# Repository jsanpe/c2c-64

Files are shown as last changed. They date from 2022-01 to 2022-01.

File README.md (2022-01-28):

# C2C-64
A Composite & S-Video to Component Video transcoder to feed older analog signals into your OSSC.

Designed with the C-64 in mind, it also supports composite and s-video signals from other systems, including the N64. A compatibility chart will soon be available in the wiki section of this project.

<p float="left">
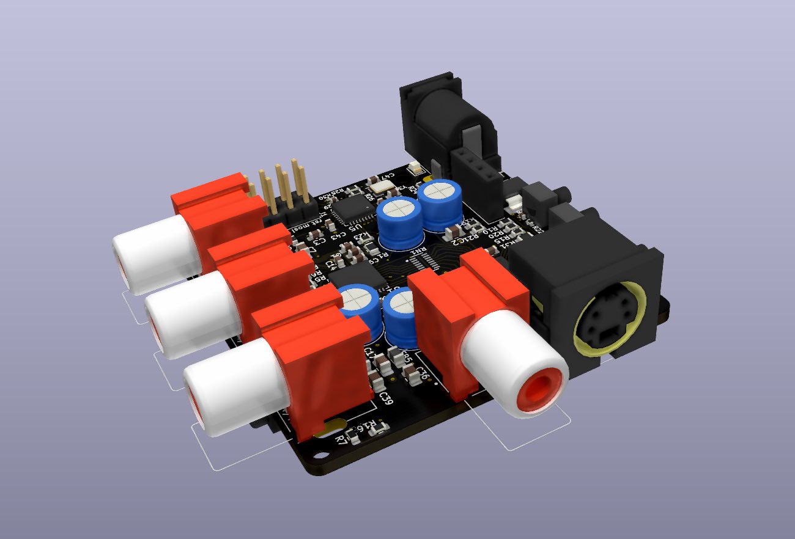
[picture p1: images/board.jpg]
C2C-64 Board Image
    
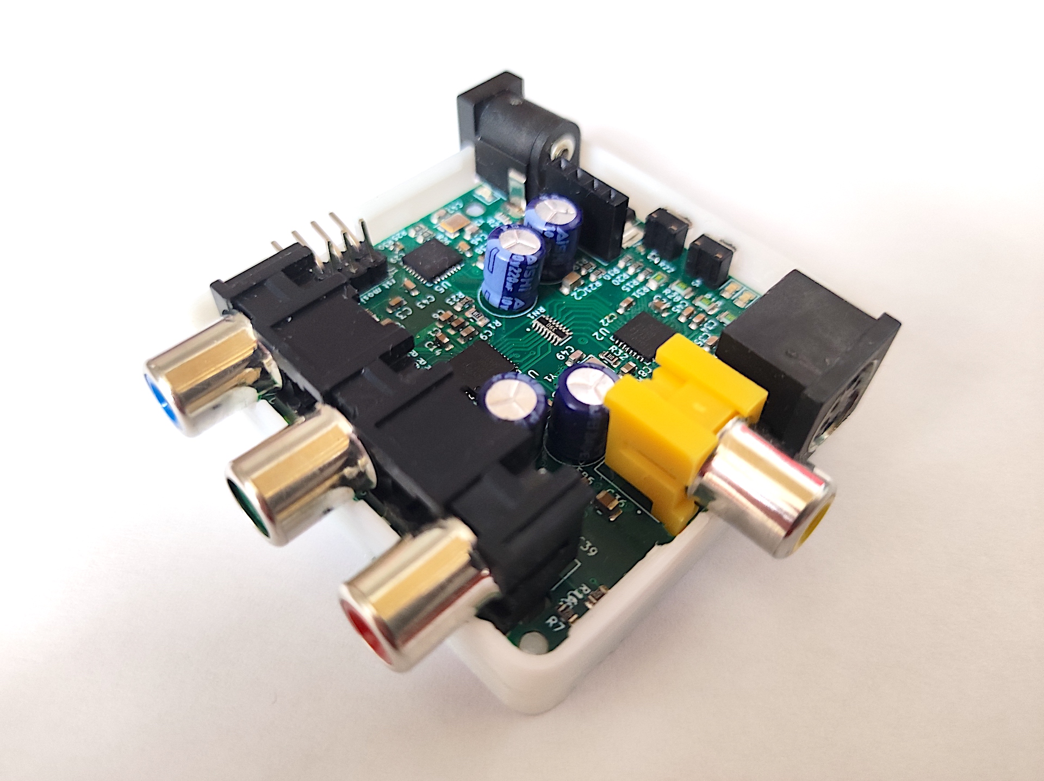
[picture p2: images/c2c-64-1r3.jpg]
C2C-64 Case Image
    
</p> 

## Description

This is an open hardware implementation of a board to convert Composite and S-Video signals into Component video. The component output from C2C-64 can be directly connected to an OSSC, effectively adding compatibility with Composite and S-Video input to this great scaler.

C2C-64 was primarily design as a simple way to connect a C64 to and OSSC. Most of the testing has been done in this platform, and presets have been chosen with it in mind. I have conducted some tests with other machines (N64, SNES, Dreamcast), although not as extensive.

C2C-64 uses a simple pipeline of video decoder and encoder to transform the input composite or S-video signals into component video. What this means in practice is that the analog input is converted to digital format and fed to the encoder to transform it into a different analog signal. This conversion is NOT lossless. However, it enables anyone to conveniently hook such signals directly into the OSSC without tinkering with the internals of their devices. 

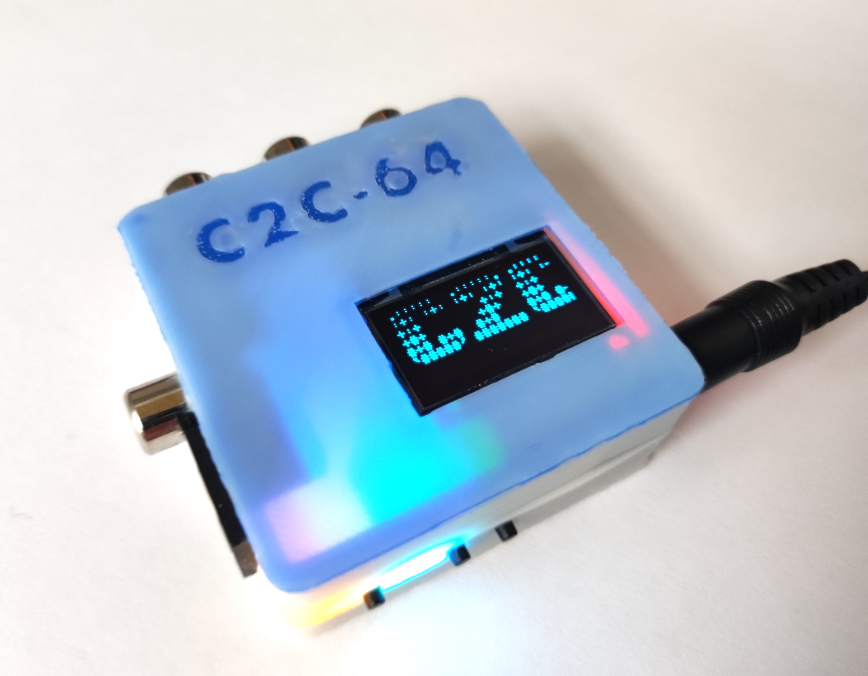
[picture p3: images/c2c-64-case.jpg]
C2C-64 Case Image


## Getting your C2C-64

This is an open project, in this repository you will find everything you need in order to build your own C2C-64.

It is important to note that building this requires ninja-grade soldering skills, especially to get those QFN ICs properly connected to the board. Also, sourcing some of the components may be a bit trickier than usual. In particular, the ADV7180 IC is unsupported by Analog anymore and probably AliExpress is the only place where it can be found at this point. There is an ADV7280(A) based version of the C2C (2R) that will be soon released, but the price of this IC is way more expensive.

I am in the process of building a first batch of 35 boards (version 1R3) that I will be selling to anyone interested in supporting the project. Reach me directly if you are interested at `com2com64@gmail.com`. I will be compiling a list and start shipping them on a first come first served basis.

You can also support the project by donating through my KoFi page 



## Comparison to Koryuu

In terms of functionality, C2C-64 provides a similar experience to the commercial product [Koryuu](https://videogameperfection.com/products/koryuu-transcoder/). However, there are notable differences between C2C-64 and Koryuu:
- C2C-64 is fully Open and Free, both Software and Hardware. Note, C2C-64 is still WiP so some parts are either missing or still in beta.
- C2C-64 has been designed to be as affordable as possible. The PCB is a 50x50mm 4 layer design, for which you can normally get special deals on PCB manufacturers. With the current shortage of electronic parts, it is difficult to estimate the total BOM cost given the huge price fluctuations. It should be possible to get the board built for well under $50 in small amounts even in these adverse conditions (half the price of Koryuu).
- The video decoding IC in the C2C-64 is the older Adv7180, compared to the more modern Adv7280 of the Koryuu. I made extensive tests, and for the intent and purposes of this board I don't think the extra cost of Adv7280 (5x the price of Adv7180) is justified. This assumption holds as long as you connect the output to an OSSC, which has de-interlacing and scaling options way beyond the possibilities of the Adv7280. An Adv7280-based version of C2C-64  already exists and will be released at some point in the future (it needs more testing and firmware changes)
- C2C-64 adds a big number of usability features to the mix (described below) making it way more flexible in terms of configuration options

## User interface

One important improvement of C2C-64 over Koryuu is the inclusion of powerful interfacing options. The board provides three main ways of allowing user interaction:
- Side switches: There are 3 switches that allow the user to perform the two most common actions: alternating the source video signal between composite and S-video; and selecting configuration profiles stored in the board EEPROM.
- UART connection: A computer can be hooked up to the board using the uart pin headers available for this purpose. Using a VT100 compatible terminal, users can configure tenths of parameters about how the video decoding/encoding is performed using menus. Such settings can then be stored as profiles in the EEPROM to be easily accessed using the side switches.
- OLED Screen: The board supports the connection of an OPTIONAL 0.96'' oled display. When the board detected that an OLED display has been connected, it will show a reduced version of the menu system offered through the UART connection, making the use of a computer to configure settings completely unnecessary.

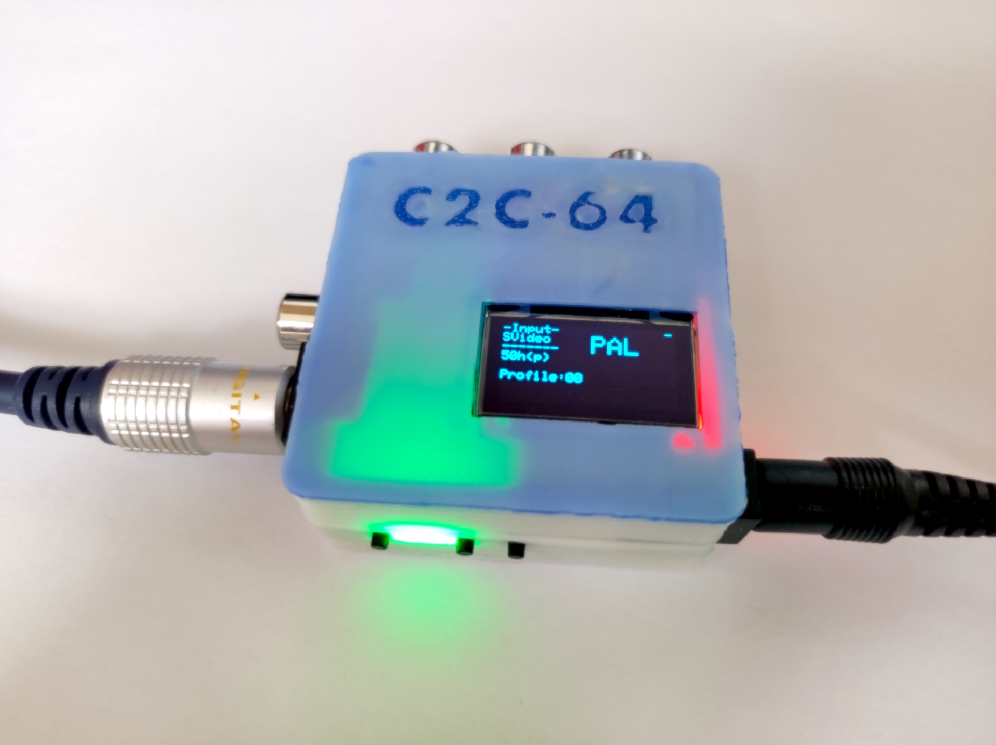
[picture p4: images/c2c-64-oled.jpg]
C2C-64 Case Image


There are also 4 leds that are used to show important signals about the operation of the board

## Important notice

This project is still WiP. The repository contains only a beta version of the firmware required to run the board. Keep checking this page for updates.

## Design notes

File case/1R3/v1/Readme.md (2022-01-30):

# Simple Case for C2C-64

It is recommended to use a case to protect the electronics of the C2C-64 from potential shorts that could result in permanent damage. This folder contains a simple case design to this end. The case is made up of two parts, bottom and top. The bottom part is enough to give good protection to the board. To insert the board on the bottom part, first push the side with the 3xRCA output and make sure that the minijack connector on the bottom side fits in the appropriate hole in the case. Then, gently press on the opposite side of the board, slightly pressing the buttons so they don't block the board on its way down. After this procedure is finished, the board will be firmly attached to the case.

There are 3 top case examples provided:
- A simple design without space for OLED screen or C2C logo
- A second design, with support for the OLED screen but no logo
- A third design, with support for the OLED screen and logo

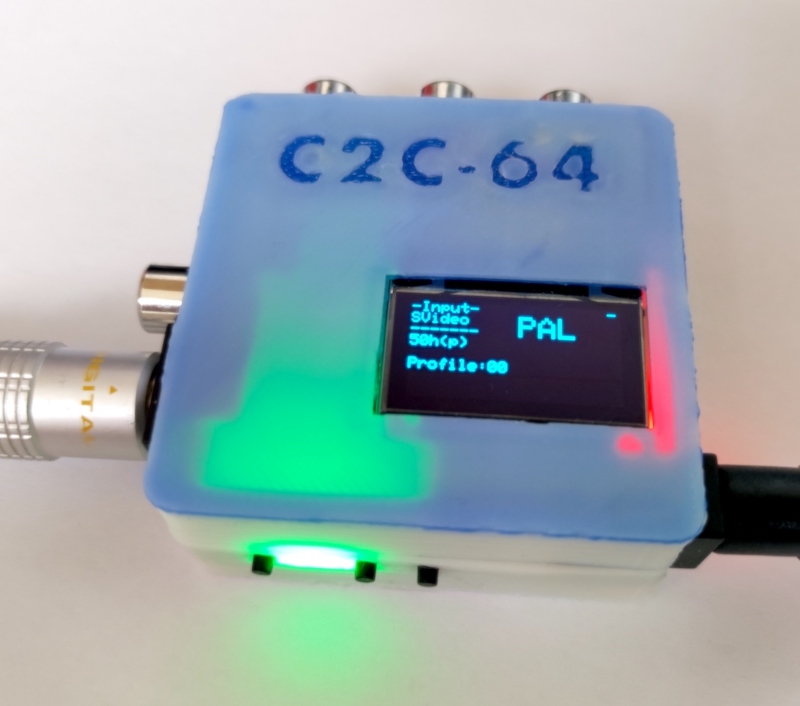
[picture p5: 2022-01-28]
images/c2c-64-oled-small.jpg

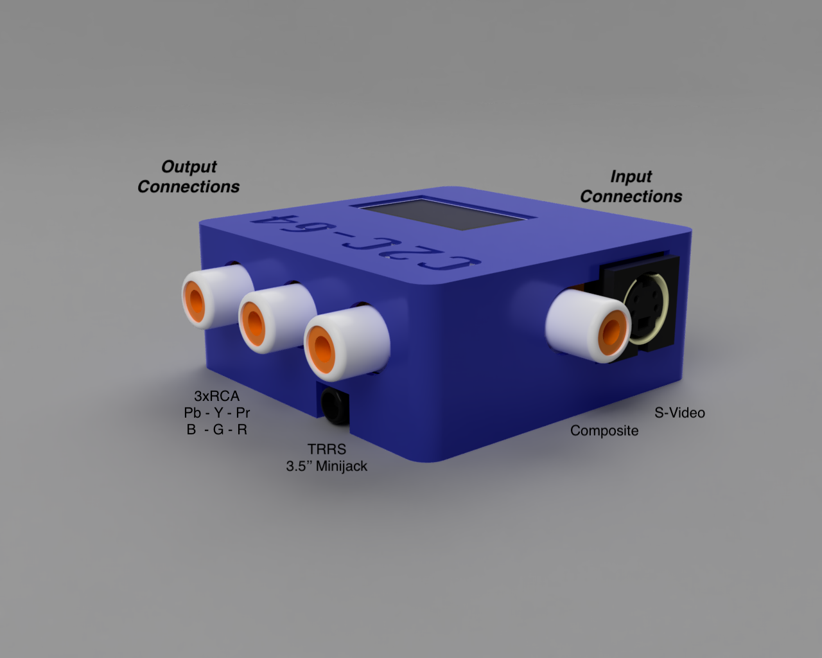
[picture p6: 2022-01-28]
images/input-output.png

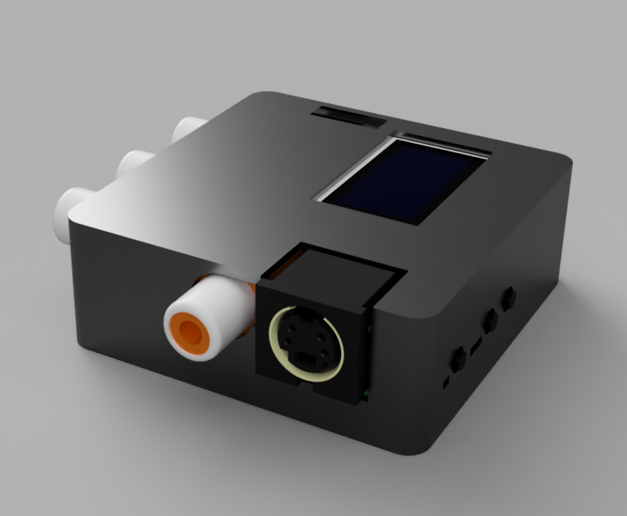
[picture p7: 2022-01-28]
images/case.png

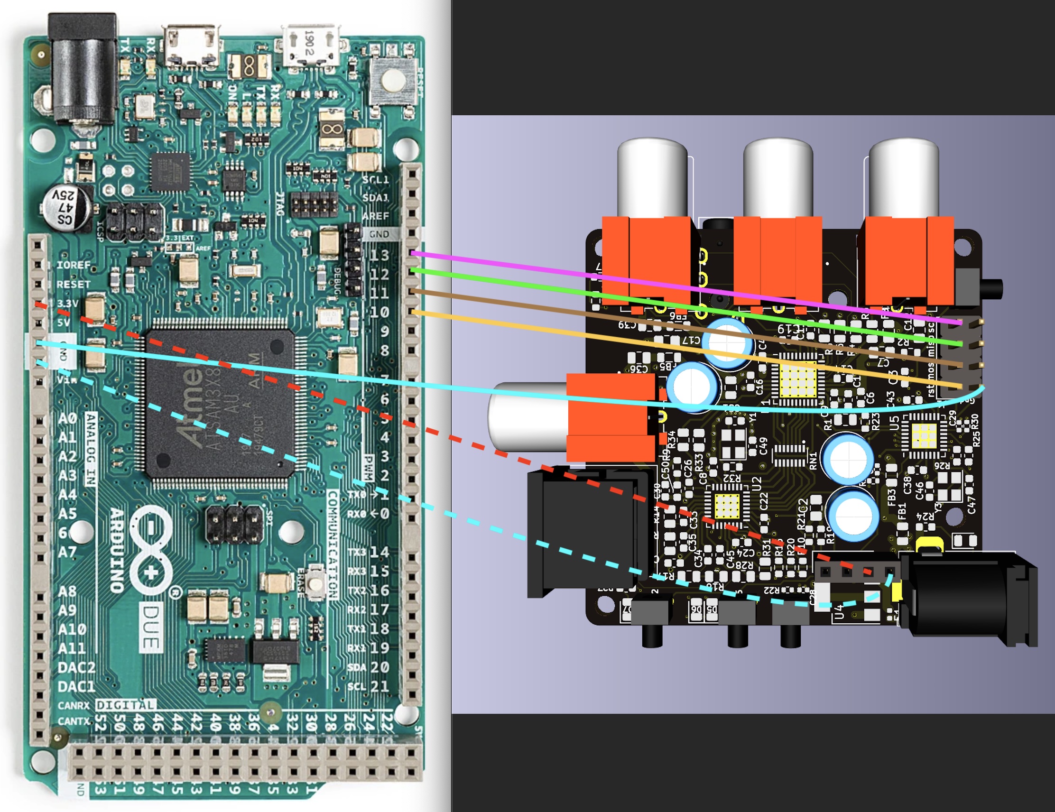
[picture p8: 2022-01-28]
images/icsp_connections.jpg

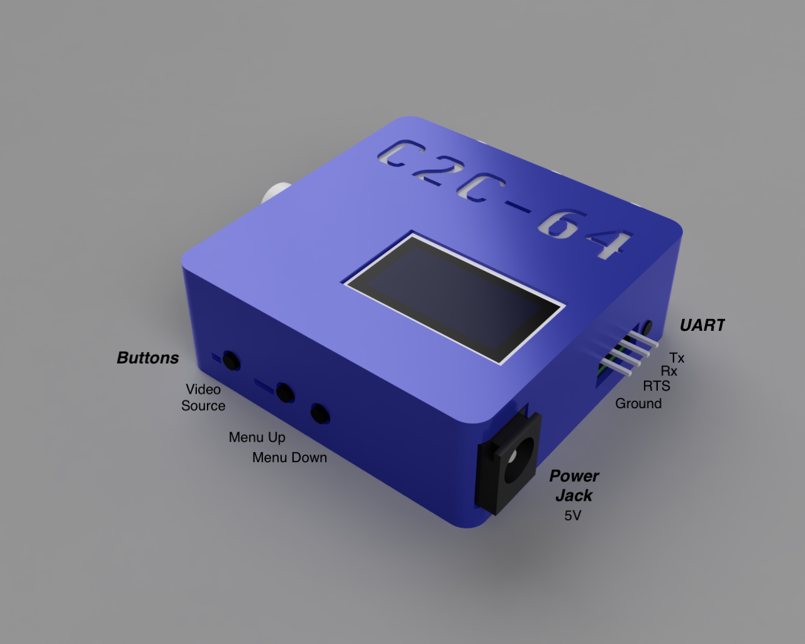
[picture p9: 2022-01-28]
images/buttons.png

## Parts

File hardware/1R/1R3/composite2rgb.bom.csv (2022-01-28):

Value | Designator | Footprint | Comments
12n | C1 | Capacitor_SMD:C_0603_1608Metric | <=5% tolerance, >=X7R
2.2n | C11 | Capacitor_SMD:C_0603_1608Metric
22u | C2,C7,C12,C17 | Capacitor_SMD:C_0805_2012Metric
82n | C30 | Capacitor_SMD:C_0603_1608Metric | <=5% tolerance, >=X7R
100nF | C3,C33,C34,C35,C38,C43,C45 | Capacitor_SMD:C_0603_1608Metric
22u | C36,C39 | Capacitor_SMD:C_0805_2012Metric
10uF | C4,C8,C9,C14,C16,C19,C22,C24,C26,C31 | Capacitor_SMD:C_0603_1608Metric
220uF | C37,C40,C41,C42 | Capacitor_THT:C_Radial_D6.3mm_H5.0mm_P2.50mm
100nF | C28,C29,C44 | Capacitor_SMD:C_0402_1005Metric
30pF | C46,C47,C49,C51 | Capacitor_SMD:C_0603_1608Metric
10n | C50 | Capacitor_SMD:C_0603_1608Metric | <=5% tolerance, >=X7R
150n | C6 | Capacitor_SMD:C_0603_1608Metric | <=5% tolerance, >=X7R
BAT54S | D1,D2,D3 | Package_TO_SOT_SMD:SOT-23
LED_R | D4 | LED_SMD:LED_0805_2012Metric
LED_B | D5 | LED_SMD:LED_0805_2012Metric
LED_G | D6 | LED_SMD:LED_0805_2012Metric
LED_Y | D7 | LED_SMD:LED_0805_2012Metric
1.5A | F1 | Fuse:Fuse_0402_1005Metric
Ferrite_Bead | FB1,FB2,FB3,FB4,FB5,FB6 | Inductor_SMD:L_0805_2012Metric
MountingHole | H1,H2,H3,H4 | MountingHole:MountingHole_2.5mm
Conn_02x04_Top_Bottom | J1 | Connector_PinHeader_2.54mm:PinHeader_2x04_P2.54mm_Vertical
RCJ-041 | J10 | RCJ-041:CUI_RCJ-041
Mini-DIN-4 | J4 | RCJ-041:CUI_MD-50S
Power | J6 | Connector_BarrelJack:BarrelJack_Horizontal
Conn_01x04_Female | J8 | Connector_PinSocket_2.54mm:PinSocket_1x04_P2.54mm_Vertical
169 | R1 | Resistor_SMD:R_0805_2012Metric
39 | R12,R18,R31 | Resistor_SMD:R_0805_2012Metric
36 | R14,R17,R28 | Resistor_SMD:R_0805_2012Metric
10k | R23 | Resistor_SMD:R_0603_1608Metric
330 | R24 | Resistor_SMD:R_0603_1608Metric
120 | R25 | Resistor_SMD:R_0603_1608Metric
220 | R26,R27 | Resistor_SMD:R_0603_1608Metric
10k | R22,R29,R30 | Resistor_SMD:R_0402_1005Metric
510 | R3 | Resistor_SMD:R_0805_2012Metric
1M | R32 | Resistor_SMD:R_0603_1608Metric
33 | R33,R34 | Resistor_SMD:R_0805_2012Metric
75 | R4,R5,R6 | Resistor_SMD:R_0805_2012Metric
4k7 | R2,R7,R10,R15,R16,R19,R20,R21 | Resistor_SMD:R_0603_1608Metric
1.69K | R9 | Resistor_SMD:R_0603_1608Metric
33 | RN1 | RCJ-041:RESCAXE50P380X160X55-16N
SW_Push | SW1,SW2,SW4,SW5 | Button_Switch_THT:mini-btn
ADV7393-Video | U1 | Package_DFN_QFN:QFN-40-1EP_6x6mm_P0.5mm_EP4.6x4.6mm_ThermalVias
ADV7180-32LFCSP | U2 | Package_CSP:LFCSP-32-1EP_5x5mm_P0.5mm_EP3.1x3.1mm_ThermalVias
TLV70018_SOT23-5 | U3,U6 | Package_TO_SOT_SMD:SOT-23-5
AMS1117-3.3 | U4 | Package_TO_SOT_SMD:SOT-223-3_TabPin2
ATmega328PB-MU | U5 | Package_DFN_QFN:QFN-32-1EP_5x5mm_P0.5mm_EP3.1x3.1mm
3xRCA_CONN | U7 | RCJ-041:TRRS-PJ-320A
3xCUI-RCJ | U8 | RCJ-041:3xCUI_RCJ-041
Crystal_GND24_Small | Y1 | Crystal:Crystal_SMD_3225-4Pin_3.2x2.5mm
16Mhz | Y2 | Crystal:Crystal_C38-LF_D3.0mm_L8.0mm_Vertical
16Mhz | Y3 | Crystal:Crystal_SMD_3225-4Pin_3.2x2.5mm
28.63 | Y6 | Crystal:Crystal_C38-LF_D3.0mm_L8.0mm_Vertical

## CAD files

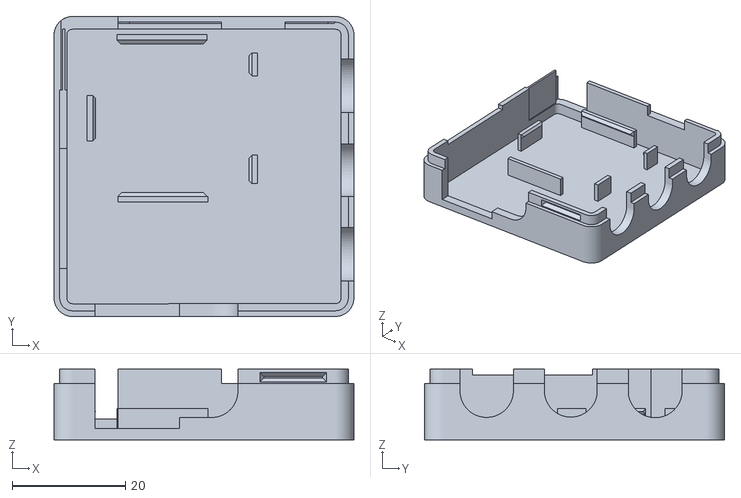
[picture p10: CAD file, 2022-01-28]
case/1R3/v1/Case_Top_Simple.stl
53.0 x 53.0 x 12.5

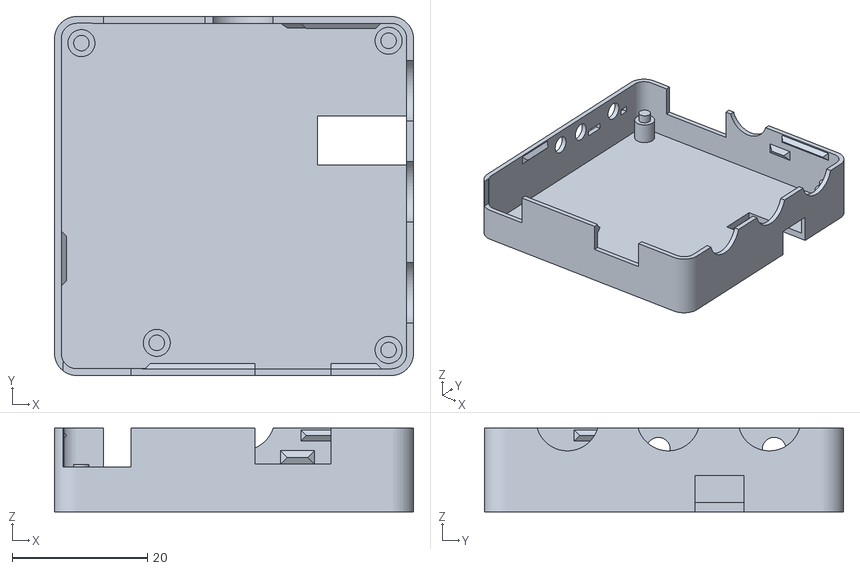
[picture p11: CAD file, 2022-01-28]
case/1R3/v1/Case_Bottom.stl
53.0 x 53.0 x 12.3

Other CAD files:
case/1R3/v1/Case_Top_Oled_Logo.stl
case/1R3/v1/Case_Top_Oled.stl

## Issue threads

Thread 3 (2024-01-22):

BOM Questions

ezcGman, 2024-01-22:
Hey there,

I'm currently collecting parts to build some of these awesome board (thanks for making these available!!).

I do have some questions about some parts:

> Ferrite_Bead	FB1,FB2,FB3,FB4,FB5,FB6	Inductor_SMD:L_0805_2012Metric

Do you have a bit more specs or an exact part number for these? LCSC (obviously) spits out a million results for just an inductor ;)

> Crystal_GND24_Small	Y1	Crystal:Crystal_SMD_3225-4Pin_3.2x2.5mm

This one is missing the frequency, do you have that by any chance?

> 33	RN1	RCJ-041:RESCAXE50P380X160X55-16N

I can't find this one anywhere with that part number. I guess from the looks and the "16N" it's some kind of multiplexer?

> 16Mhz	Y2	Crystal:Crystal_C38-LF_D3.0mm_L8.0mm_Vertical
> 28.63	Y6	Crystal:Crystal_C38-LF_D3.0mm_L8.0mm_Vertical

Are those actually on the board still? I struggle to find them when looking at the gerbers in a gerber viewer. I was struggling to understand the package size / footprint of these, so I tried to find them on the board and see what they look lilke.

And on another note: In case you are using KiCad, I **highly** recommend using this plugin: https://github.com/openscopeproject/InteractiveHtmlBom

It's absolutely fantastic and generates interactive / HTML BOM files which are a tremendous help when soldering such a board. You can get an idea what they look like here (just download and open the HTML): https://github.com/ezcGman/lora-gateway/tree/master/pcbs/LoRa-Gateway-E32/ibom

Thanks and greetings,

Andy!

jsanpe, 2024-01-22:
Hi,
thanks for reaching out. Sorry about the poor state of the project, I unfortunately have little time these days to maintain/improve it.
Regarding your questions:
- For ferrites I used these: https://www.lcsc.com/product-detail/Ferrite-Beads_Sunlord-GZ2012D601TF_C1017.html but they seem to be out of stock nowadays. You should be able to find something with similar characteristics in lcsc (or elsewhere)
- For crystals, note that Y1 and Y6 are mutually exclusive. You should use one or the other, depending on availability. The freq is 28.636363Mhz. I have used this one in the past: C136080.
- The same applies to crystals Y2/Y3, you can choose either one. However, this crystal is not needed as the MPU internal oscilator is used by default. So, you can leave this (and the caps C46 and C47) unpopulated.
- RN1 is a resistor array. 33 ohm is recommended, but you can use something close to it if you don't find it. I actually have been using this part: C78520 which is 39ohm

I will try to use the plugin you recommend and push the output to github. I can't really commit to this, lot's of other stuff in my life right now.

jsanpe, 2024-01-22:
It was easier than I expected: https://github.com/jsanpe/c2c-64/tree/master/hardware/1R/1R3/bom

ezcGman, 2024-01-22:
> Hi, thanks for reaching out. Sorry about the poor state of the project, I unfortunately have little time these days to maintain/improve it. Regarding your questions:
>
> * For ferrites I used these: https://www.lcsc.com/product-detail/Ferrite-Beads_Sunlord-GZ2012D601TF_C1017.html but they seem to be out of stock nowadays. You should be able to find something with similar characteristics in lcsc (or elsewhere)

They're still in stock for me using that link, added them to the cart, thx!

> * For crystals, note that Y1 and Y6 are mutually exclusive. You should use one or the other, depending on availability. The freq is 28.636363Mhz. I have used this one in the past: C136080.

Oh ok. I just looked at the BOM, was there a note about that somewhere that I missed? I added the C136080 to the cart: https://www.lcsc.com/product-detail/Crystals_HELE-Harmony-Elec-X3S02863ADK1HA-X_C136080.html

> * The same applies to crystals Y2/Y3, you can choose either one. However, this crystal is not needed as the MPU internal oscilator is used by default. So, you can leave this (and the caps C46 and C47) unpopulated.

Ah ok. So that one is not even used at all? So there is really no need for it? I might just add it, because it's just a few cents, if there is the slightest chance for it to make any sense :)

> * RN1 is a resistor array. 33 ohm is recommended, but you can use something close to it if you don't find it. I actually have been using this part: C78520 which is 39ohm

Aaaaah yeah 🤦 That makes sense, thanks! LCSC doesn't have it in stock, will get it somewhere else.

Will continue adding everything to the cart, thanks already!!

Greetings,

Andy!

ezcGman, 2024-01-22:
Some questions on the fuse:
* Guessing 6v is fine, as everything is 5v on the board?
* Is the 1.5A the tripping or hold current? Guessing it's trip current?

Thanks!

jsanpe, 2024-01-23:
For fuse I used this: C311043. 6V is a bit tight, but you can always replace it if it blows too easily. At 1.5A you should use a fast fuse. The board consumption should be in the few mA range (300mA tops) but it's always higher when you switch it on, that's the reason I allow for some extra amps. You may want to go for a slower fuse with lower amp rating.

About Y2/Y3 the current firmware does NOT use them. The internal atmega oscillator is accurate enough to allow for UART to work fine at slow speeds. For all other intents and purposes the accuracy of the oscillator is simply irrelevant, as the MPU is only there to configure the Video encoder and decoder ICs. My recommendation: do not populate.

ezcGman, 2024-01-23:
One more sadly :D Do you by any chance have a link to the buttons you used? There are a quadrizillion buttons out there and finding the ones you used with the spacing... it's close to impossible :D Thanks!

jsanpe, 2024-01-23:
> One more sadly :D Do you by any chance have a link to the buttons you used? There are a quadrizillion buttons out there and finding the ones you used with the spacing... it's close to impossible :D Thanks!

These little f$ckers are hard to find, tell me about it. Try these: C961730

ezcGman, 2024-01-24:
Thanks for your extensive help!

I've ordered everything, most from LCSC and some connectors from AliExpress. I'm attaching the CSV of my LCSC order for people to easier re-order the components. Also, there are the items on AliExpress I ordered:

* https://www.aliexpress.com/item/1005004682978457.html
* https://www.aliexpress.com/item/4001206395694.html
* https://www.aliexpress.com/item/1005006152724809.html
* https://www.aliexpress.com/item/1005003406780797.html

[LCSC_Exported__20240124_210810.csv](https://github.com/jsanpe/c2c-64/files/14038775/LCSC_Exported__20240124_210810.csv)
**ATTENTION:** A few caps are missing from this CSV, as I still had them in stock here. Forgot which ones these were. I'll update this post as soon as I receive the order, so I can easily see what's missing, so what I need to get out of my personal stock.

ezcGman, 2024-01-26:
Will do! I've updated the CSV to now reflect the full components list, so people can just use that :) Closing this for now :)

whytheheckme, 2024-05-07:
@ezcGman Did you ever get this up and running? Do you have spare parts you'd like to sell (particularly a PCB?)

ezcGman, 2024-05-08:
> @ezcGman Did you ever get this up and running? Do you have spare parts you'd like to sell (particularly a PCB?)

Jepp, I did: https://github.com/jsanpe/c2c-64/issues/5

And yeah, I do have complete (just missing the screen, but that is easy to get via AliExpress) left over kits I can sell. Because I bought parts for 5 kits directly, the price per kit is actually super low, it's just below 20€! I can spare one, if you want it? I'm in Germany, so depending on where you are, shipping costs may be the same as the price for the kit ;)

whytheheckme, 2024-05-08:
> And yeah, I do have complete (just missing the screen, but that is easy to get via AliExpress) left over kits I can sell. Because I bought parts for 5 kits directly, the price per kit is actually super low, it's just below 20€! I can spare one, if you want it? I'm in Germany, so depending on where you are, shipping costs may be the same as the price for the kit ;)

Amazing! I just finished pricing out all of the parts and the PCB, and I really don't need more than one, so I think it would be worth it. I live in the US but have an address in Denmark you can send it to where I will be in about 10 days (I found I could generate a label for 12€ but you may be able to get it even cheaper!)

Can you drop me a line? jake.at.spam (at) gmail
Thank you!!

whytheheckme, 2024-05-10:
@ezcGman Just wanted to follow up, I'd love to connect and buy a kit set from you.

Closed 2024-01-26.

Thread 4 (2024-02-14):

Question about orientation of ICs

ezcGman, 2024-02-14:
Hey there (again) :)

I was just about to solder one of these and then realized that the PCB is missing the usual dot indicators to tell about the orientation of the ICs. I saw that the silkscreen/graveyard on one side is open instead of closed. Is that the orientation indicator?

Talking about this:
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

Thanks and greetings,

Andy!

jsanpe, 2024-02-15:
Yup, Kicad's default footprints indicate pin number 1 using the open angle, as you mentioned

ezcGman, 2024-02-15:
Ou, never realized. I also use KiCAD but that I never saw.
Thanks!! Off to the workbench then \o/

Closed 2024-02-15.

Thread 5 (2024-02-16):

Failing to program via UART (and maybe also to transfer the bootloader)

ezcGman, 2024-02-16:
Hey there,

it's me again... I finished building the board and everything looks fine, but I struggle a bit to get it flashed via UART. And now I'm not even sure if I did everything right for the fuses and bootlader.

I'm using this for reference: https://github.com/jsanpe/c2c-64/wiki/Programming-the-C2C-64

First, I don't have an Arduino DUE, but I googled a bit and it seems that you can also use an ESP8266 or ESP32 (which I work with A LOT) to achieve the same. So I successfully flashed the ArduinoISP sketch (it just compiles naturally, I just needed to change some pins) to a random ESP8266 (Actually a NodeMCU) I had using ArduinoIDE. Then (because you're using/referencing a platformio.ini file) I opened my VS.Code which I also use a lot to flash ESPs using platformio, so I'm pretty familiar with that.

That's how it's wired (c2c is powered using my bench PSU, set to 5v 2A):
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

I opened the "fuses_1R3" task, changed the upload_port to "COM4" (as I'm on Windows) and I could successfully run the "Set Fuses" and "Burn Bootloader" platform tasks (which is I guess what you're referencing in your guide). Both worked successfully, see the output at the end of this post.
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

I then took my FTDI dongle (which uses a FT232BL chip (https://www.aliexpress.com/item/32967622307.html)) and tried to flash the software via UART, but I always get the same error: `avrdude warning: attempt x of 10: not in sync: resp=0x00`

Yes, sadly my dongle doesn't have an easy way to wire RST, but it has the pin exposed, so I'm touching it manually. But no matter how often I try, I always get the same error. I also tried simply bridging RST of the c2c to GND manually but it never works. No matter how often I try and when... It never works. I even tried reversing TX/RX, just in case: Still nothing.

Then I thought, after reading your guide 100th time: "Did I actually flash the bootloader?", as I just used the platform task "Burn bootlader". I then got my ESP wired again, validated I can still execute "Set Fuses" and then just hit "Upload" (still under the "fuses_1R3" task), but it first failed with not finding the "SSD1306Ascii" library, because it's missing in the "fuses_1R3" task. Added it and hit "Upload" again. It compiled but then getting the same error as I got via UART: `avrdude warning: attempt x of 10: not in sync: resp=0x00`

I'm a bit lost what I'm doing wrong... Do you maybe have an idea what's happening? I don't think my board is broken, right? Otherwise I wouldn't be able to execute the platform tasks "Set Fuses" and "Burn Bootloader" successfully, right? :/

Which USB FTDI dongle are you using? I might just get a different one; not really trusting this one here with the weird RST pin...

Thanks so much again and greetings,

Andy!

P.S.:
Some outputs:
Set Fuses:
```
Executing task: C:\Users\andy\.platformio\penv\Scripts\platformio.exe run --target fuses --environment fuses_1R3

Warning! Ignore unknown configuration option `build_unflags` in section [platformio]
Warning! Ignore unknown configuration option `build_flags` in section [platformio]
Warning! Ignore unknown configuration option `monitor_port` in section [platformio]
Warning! Ignore unknown configuration option `monitor_speed` in section [platformio]
Processing fuses_1R3 (platform: atmelavr; framework: arduino; board: ATmega328PB)
--------------------------------------------------------------------------------------------------------------------------------------------------------------------------------------------------------------------------------------------------------------------------------------------------
Verbose mode can be enabled via `-v, --verbose` option
CONFIGURATION: https://docs.platformio.org/page/boards/atmelavr/ATmega328PB.html
PLATFORM: Atmel AVR (5.0.0) > ATmega328PB
HARDWARE: ATMEGA328PB 8MHz, 2KB RAM, 32KB Flash
PACKAGES:
 - framework-arduino-avr-minicore @ 3.0.0
 - tool-avrdude @ 1.70200.0 (7.2.0)
 - toolchain-atmelavr @ 1.70300.191015 (7.3.0)
LDF: Library Dependency Finder -> https://bit.ly/configure-pio-ldf
LDF Modes: Finder ~ chain, Compatibility ~ soft
Found 10 compatible libraries
Scanning dependencies...
Dependency Graph
|-- Wire @ 1.1
|-- mcurses @ 0.1
|-- SSD1306Ascii @ 1.3.5
Building in release mode

TARGET CONFIGURATION:
---------------------
Target = atmega328pb
Clock speed = 8000000L
Oscillator = internal
BOD level = 2.7v
Save EEPROM = yes
Bootloader type = urboot
UART port = uart0
Clock output = no
CFD enable = no
---------------------

Selected fuses: [lfuse = 0xe2, hfuse = 0xd7, efuse = 0xf5]
Setting fuses
avrdude: AVR device initialized and ready to accept instructions
avrdude: device signature = 0x1e9516 (probably m328pb)
avrdude: erasing chip

avrdude: processing -U lock:w:0xff:m
avrdude: reading input file 0xff for lock
         with 1 byte in 1 section within [0, 0]
avrdude: writing 1 byte lock ...
avrdude: 1 byte of lock written
avrdude: verifying lock memory against 0xff
avrdude: 1 byte of lock verified

avrdude: processing -U hfuse:w:0xd7:m
avrdude: reading input file 0xd7 for hfuse
         with 1 byte in 1 section within [0, 0]
avrdude: writing 1 byte hfuse ...
avrdude: 1 byte of hfuse written
avrdude: verifying hfuse memory against 0xd7
avrdude: 1 byte of hfuse verified

avrdude: processing -U lfuse:w:0xe2:m
avrdude: reading input file 0xe2 for lfuse
         with 1 byte in 1 section within [0, 0]
avrdude: writing 1 byte lfuse ...
avrdude: 1 byte of lfuse written
avrdude: verifying lfuse memory against 0xe2
avrdude: 1 byte of lfuse verified

avrdude: processing -U efuse:w:0xf5:m
avrdude: reading input file 0xf5 for efuse
         with 1 byte in 1 section within [0, 0]
avrdude: writing 1 byte efuse ...
avrdude: 1 byte of efuse written
avrdude: verifying efuse memory against 0xf5
avrdude: 1 byte of efuse verified

avrdude done.  Thank you.

================================================================================================================================== [SUCCESS] Took 3.49 seconds ==================================================================================================================================

Environment    Status    Duration
-------------  --------  ------------
fuses_1R3      SUCCESS   00:00:03.486
================================================================================================================================== 1 succeeded in 00:00:03.486 ==================================================================================================================================
```

Burn Bootloader:
```
Executing task: C:\Users\andy\.platformio\penv\Scripts\platformio.exe run --target bootloader --environment fuses_1R3
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
ezcGman, 2024-02-19:
The flasher you use just arrived and it sadly also doesn't work :( Same error as above (0x00). I tried reversing TX/RX, I tried using RTS and CTS: Both don't work :(

I'm clueless what it can be... I also multimetered the pin header pins and the pads on the atmega: they have continuity, so... I have no clue :D
I'll try lowering the baud rate and see if that will help...

jsanpe, 2024-02-19:
Hi! Sorry to hear the new flasher is not working :( I was starting to think that the programmer wasn't the issue after the many tests you've been making.

Answering your question about C3 and R2, this is the reset circuit that is triggered by the RTS pin. Once the reset happens, the bootloader enters into action and gives you 1 or 2 seconds to start sending the data through uart. If this reset circuit does not work, then the bootloader never listens for a new firmware. TX and RX are connected directly to the MCU. That's ok.

I've been checking out the MiniCore project and it seems that there has been a change in the bootloader used. I wonder if this could be the issue. This can be tested quite quickly, change the line:
`upload_protocol = arduino` in env Board_1R3 to `upload_protocol = urclock`
Or you can force the use of the previous bootloader (optiboot) by setting
`board_hardware.uart = optiboot` on the Board_1R3 env

Another quick check to verify if the bootloader is running is to place a led with a current limiter resistor on the RST pin (right above the TX pin). The bootloader should either blink it or completely switch it on on boot.

Hope this helps, and sorry for all the trouble. If this does not work, then I will recommend to flash through the ICSP header.

jsanpe, 2024-02-19:
Hi again,

I've been doing some more reading and after inspecting the firts log you sent me I've found this message:
```
Building in release mode
Using bootloader image:
C:\Users\andy\.platformio\packages\framework-arduino-avr-minicore\bootloaders\urboot\atmega328pb\watchdog_1_s\autobaud\uart0_rxd0_txd1\led+b5\urboot_atmega328pb_pr_ee_ce.hex
```
which means you have flash urboot bootloader. Again, this is new for MiniCore (which is the backbone of C2C) and was introduced in version 3.0.0 in Oct 2023. So I was not aware of this change. I think this is what's behind the issues you are facing. Replace the `upload_protocol` as I told you in the past message, that should fix the issue straight away.

There's more info about the new bootloader [here](https://github.com/stefanrueger/urboot) and these is the avrdude command they recommend using:
`avrdude -c urclock -p m328p -b 115200 -P /dev/ttyUSB0 -U flash:w:mysketch.hex:i`

Again, I think this should solve the issues you are facing. I really hope this time it helps.

ezcGman, 2024-02-19:
HOLY MOTHER OF GOD, IT WORKED!! :D YOU ARE A GENIUS!!! \o/ Even with my old flasher \o/
THANKS SO MUCH!!!!

So the only changes I now ended up going to the current version of `platformio.ini` in your repo is:
* Under `[env:Board_1R3]` setting this `upload_protocol = urclock`
* And for me / under Windows under `[env:fuses_1R3]` setting `-PCOM4`

And confirming my packages and versions for people to come:
```
PACKAGES:
 - framework-arduino-avr-minicore @ 3.0.0
 - tool-avrdude @ 1.70200.0 (7.2.0)
 - toolchain-atmelavr @ 1.70300.191015 (7.3.0)
```

Can't wait to test the board now!!

jsanpe, 2024-02-20:
Nice! Thanks for having the patience mate, and sorry for all the trouble. This change of bootloader in MiniCore was something I wasn't aware of. And it comes with some breaking changes :( It seems to be a much better/modern bootloader, so the change is for good. But you were the first one to face it.

I will update the platform.ini file in the project with the new upload protocol, which apparently is backwards compatible with arduino.

Enjoy your new C2C!

ezcGman, 2024-02-20:
Absolutely no issue, this is a DIY board, these things can and may happen! Thanks to you for the extensive support here!!

I'll try to give it a test this week, packed week this is! I'll follow up with a tiny post/instructions how I used an ESP to flash the bootloader, instead of an Arduino Due. Think this is prettx useful, as everybody probably has an ESP8266/ESP32 somewhere. And if not: It's not even 5€ :)

Later,

Andy!

jsanpe, 2024-02-20:
Thanks Andy, if you can write those instructions I can add them to the wiki along with the DUE so people have more options. Let me know if that's ok!

Jose

jsanpe, 2024-02-20:
Neat, thanks so much! I'll add this to the wiki and ensure proper credit is given.

I have already updated the platform.ini file in the repo. It should work fine for both optiboot and urboot now.

jsanpe, 2024-02-20:
Wiki updated!
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

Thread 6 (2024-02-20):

PCB silkscreen or IBOM suggestions

ezcGman, 2024-02-20:
Hey again :D

While building the board, I realized a few places where the PCB and the IBOM was missing orientational indicators for a few parts. I was able to sort it out by multimetering, but still wanted to leave the suggestions here:

* The radial caps are missing orientation / GND indicators
* The SMD LEDs are also missing the orientation / GND indicators
* The resistor array has an orientation indicator, but it doesn't need one
* MAYBE improve the orientation indicator for the ICs, away from the single / open graveyard silkscreen to the typical dot?
* Bring the UART pin namings to the back, as you can't read them anymore when a pin header is soldered on?
* You have a few overlapping silkscreens, like U8 and R16, or C11 & C19, etc. They also have different font sizes, maybe making them all the smaller size gives you the space needed?

That's it :D I just close it right away; you can just ignore if you want, just wanted to bring them up ;)

jsanpe, 2024-02-21:
Thanks for the feedback, I'll keep it in mind for the next project update.

Closed 2024-02-20.

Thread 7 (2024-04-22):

Looking for a pick and place file

khari05, 2024-04-22:
I'm trying to make my own board and thought I'd try to make JLC assemble the SMD components on the top side. In KiCad, there's a fabrication output option called "Component Placement" and you can set the output format to CSV. If you share the KiCad project, I can tinker with it to get only the components I need. If not, I'd appreciate a component layout CSV for the front.

jsanpe, 2024-04-23:
Hi, sorry for the late response. Really busy times for me. I have found the pos file I think I used back in the day. Give it a try, it should work fine.
[composite2rgb-top-pos.csv](https://github.com/jsanpe/c2c-64/files/15082444/composite2rgb-top-pos.csv)

cheers

khari05, 2024-04-24:
Thank you so much for your reply! This will save me so much time.

I have a few questions about the BOM:
- does R1 need to be 169Ω? I'm trying to mostly use basic components from JLC, and it doesn't seem like I can find a similar value. Might end up purchasing them separately and soldering it by hand
- Is it okay to replace R4,R5,R6 with 0603 resistors? They look like termination resistors, so I don't think any current will run through them.

Other than that, I think I am just going to hand solder anything I can't find as a JLC basic component other than the main ICs since the $3 reeling fee per extended component can be hefty

jsanpe, 2024-04-27:
Hi,

about R1, it is part of the video encoder PLL circuit along with C1 and C6. All these are pretty critical parts, and it is recommended to use high quality components with little tolerances for them.

R4-R6 can be replaced with 0603 components without any issue.

cheers!

khari05, 2024-05-16:
Thank you for helping! I got the partially assembled boards in the mail and my first one will be ready for testing once my hotplate arrives and I can rework RN1 (I accidentally bridged the contacts on it)-- I really should've paid to not have to hand solder it.

My total for boards + components was ≈$40 USD per board because of shipping and since I paid the $3 setup fee per component for the major ICs to be pick-and-placed by JLC

Closed 2024-05-16.

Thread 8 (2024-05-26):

Throwing an error to the UART console

khari05, 2024-05-26:
Is the c2c64 supposed to throw an error to the UART console when there isn't an OLED display attached?

I have an NTSC NES attached to the board and have tried both directly to an LCD TV and through a GBS-C scaler, and am getting no video output. I will send the error shown on my console and test it with a cartridge that outputs at a different framerate tomorrow since that could have something to do with it.

When testing, I also noticed that the TLV70018 was getting fed 5V to step down to 1.8V, is this normal? The voltage regulators seem to be getting warm when powered on for a while.

khari05, 2024-05-26:
After tracing the error, I think `0x02` means the ADV7180 did not reply to the power on request on the I2C bus. Are there any components you would recommend for me to check for issues?

jsanpe, 2024-05-26:
You are correct, that error signals an issue in the initialization of one of the video ICs, in this case the 7180. Things to check:
- Have a look at the output of all the regulators, but it's probably not a power problem given the encoder seems to be initializing ok, as well as the MCU.
- 99% of the times I got this error it was because of a bad soldered IC. These little f$ckers are not easy to solder correctly. For the IC to initialize ok, you just need to have power, gnd, sda, scl and reset working. One of these is probably not well connected/soldered

Good luck debugging the issue, let me know if I can help

khari05, 2024-06-04:
I went and probed around, and traced the board, and noticed that C26 is only reading 1V... I found that U6 and its capacitor, C41 are both reading 1V.

I'm not sure how the encoder chip is responding properly since one voltage regulator just isn't working

jsanpe, 2024-06-04:
Hi,

U6 is the PLL power supply, shouldn't really affect the boot up of either the encoder of the decoder but perhaps the decoder is a bit more anal about it. Question now is what's failing, is it the regulator? Perhaps there something shorted somewhere in the board. If you have a spare just replace this regulator and measure voltages again.

Jose

khari05, 2024-06-04:
Thanks for your reply! That's exactly what I am going to do. I'll have to double-check the TLV70018 datasheet to see if it is even capable of dropping to 1V without being a faulty unit

jsanpe, 2024-06-04:
Note that if there is a short or a broken part somewhere in the rail, it may be pulling down the voltage to 1V. There's a bunch of bypass caps that connect the rail to ground directly, it could be one of these. Measure resistance between the output of the regulator and gnd, just in case.

khari05, 2024-06-04:
I think I've figured out what's wrong. The enable lead of my regulator wasn't getting 5v, which lead me to figure out that it's not soldered properly... the 1V reading is likely just from the 1.5µA leakage current that it's rated for. Fixing this made the ADV7180 initialize correctly...

Now I have a new error:
```
Oled NOT detected

Error init::0x00|0x0A
```

khari05, 2024-06-04:
I think this error means that there were either 5 NACK signals or it timed out twice

khari05, 2024-06-04:
UPDATE: I checked the voltage regulators and after fixing them, it trips the fuse during power on.

jsanpe, 2024-06-05:
Hi there, the 0x0A seems to be an undetected Encoder but I think you had that figured out already.

It's a bit unclear what happened next. There was another issue with the regulators that you fixed? Bypassing the fuse could be dangerous, what type of fuse are you using? what specs? The board may generate a bit of a current rush when in first powers on, but it should go pretty low pretty quick (200ma or so).

Regarding NTSC signals, some people have tested the board extensively with NTSC gear in the US and there are no specific issues with this. The ICs support most standards (PAL, NTSC, SECAM) and have the ability to autodetect and configure themselves for the input signals.

What device are you trying to visualize with the c2c? is it composite or svideo? Remember there is a button to select the input, which defaults to composite. Also, the OLED screen should display information about the signal being transcoded and there's a green led that should be on when an input signal is locked.

jsanpe, 2024-06-06:
Hi again,

I'm still unsure if you were able to solve the 0x0a encoder init error. I assume you did. In that case, what was the problem and how did you solve it?

About the fuse, the fact that you are having to bypass it indicates a potential problem with your board, either a short somewhere or a faulty part. It shouldn't just trip.

About the signal, one thing to have in mind is that the output will be identical in frequencies to the input. I've found that my tv was not able to sync to Commodore 64 15khz output, however OSSC had no problem. In general, GBS-C is known to work with C2C without any changes. Are you using the gbs control fw or the original? I haven't tested this in a while, perhaps newer versions do not work. I'll check this afternoon.

I recommend adding an OLED screen to the c2c to simplify the debugging.

jsanpe, 2024-06-06:
I just remembered that gbs control was unable to sync to c2c out of the box. The coasting setup in the gbs firmware is too tight for the signal generated by the encoder in the c2c. How does the c2c->gbs output look like? Could you describe it?

The solution is pretty easy, you need to tweak with the coasting controls. I am not sure if the gbs UI allows you to do that though. Back in the day I remember I had to change the coasting constants in two lines of the code. I need to have a look again, I just don't remember the details. Do you think you could flash a new fw into your gbs if I send you a tweaked version?

khari05, 2024-06-07:
The output I was getting to my VGA PC CRT monitor, from my GBS-C was somewhat green while the desynchronized grayscale output from the NES was somewhat overlaid.

I tested it with an LCD TV by plugging the output of the c2c64 directly into the component input of the TV. The TV is a low-end model from a decade ago, and was sometimes getting a grayscale variant of the desynced image I got from the GBS-C to my VGA CRT, so the TV could have been improperly showing data because of something in the TV.

khari05, 2024-06-07:
Suspecting that it may have something to do with data traveling between the decoder and encoder, I tested the solder joints of RN1 and found at least one joint that isn't making contact. I will fix it then try it again. Thank you for all of your advice.

khari05, 2024-06-07:
I have now (hopefully) fixed RN1. The fuse isn't tripping anymore either... I think the video encoder was consuming obscene amounts of energy trying to encode garbage into component.

Now, the output I'm getting seems somewhat less like a hardware issue:

https://github.com/jsanpe/c2c-64/assets/35894769/0947d976-b606-487d-8407-70c39986a111

It still isn't syncing correctly, but it appears to be outputting some color information.

My LCD TV is also not syncing correctly, but it seems to only be displaying in grayscale, compared to the GBS-C, which is pushing *some* color information.

khari05, 2024-06-07:
> I'm still unsure if you were able to solve the 0x0a encoder init error. I assume you did. In that case, what was the problem and how did you solve it?

Yes, I traced in the code that 0x0A could be caused either by no reply from the encoder IC or a timeout for the last two commands. I checked the voltage between FB4 and GND, and read 0.8v. This low voltage seems to always mean leakage current from a disabled TLV70018. I found the solder joint on the EN pin of U3 was also somewhat loose, and I could trace the next issue (fuse) after that.

The fuse was likely caused by the video encoder consuming obscene amounts of energy trying to encode the floating inputs from the bad solder joint on RN1.

khari05, 2024-06-16:
I plugged in a Sony camcorder over S-Video and saw that the "Sync" value was showing Y. I was having an issue with F1 tripping, however. Deciding that it must be caused by solder joints between the decoder and encoder, I resoldered RN1 (again), and replaced F1.

I found that the sync issues were definitely caused by the encoder chip since the output was now clean, and syncing on both my GBS-C and LCD. This is what the output looks like now:

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

I was testing to see if only one color channel is having issues, and found that if I disconnect Pr, I got a clean signal.

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

This happens on both S-Video, and Composite, on both my GBS and LCD. I suspect there is either an issue near the red channel, or one of the solder joints on RN1 is not happy, if one of the pins carries data specifically in the red channel. I will check the datasheet soon and let you know if this is also caused by RN1.

jsanpe, 2024-06-18:
Hi there,

If the problem is limited to the red channel, I would first look at D1 and R4, which are directly connected to the Red channel output. Check if they are correctly soldered, and working correctly. Otherwise the issue could be in pad 26 of the ADV7393, perhaps it's not making good contact.

khari05, 2024-06-19:
I suspect D1 is likely related to the issue. I will check it out on my oscilloscope soon and let you know what I find

khari05, 2024-07-05:
AND AFTER HOURS AND HOURS OF TROUBLESHOOTING, I ATTACHED RN1 CORRECTLY...

I discovered that all of my issues were caused by RN1 still not being attached properly. Almost all the pins were connected except one specific pin. I should have probed the individual pins of that resistor array with my oscilloscope much much earlier. If I did, I would've traced this much faster. It works! This is my first major soldering project where I ordered a PCB that I didn't design myself. Quite the learning experience.

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

Over the course of this project, I figured out how to create color bars on the composite port of a raspberry pi zero so that I could have a consistent waveform when viewing the output signals on my analog oscilloscope.

Thank you for all of your help!

jsanpe, 2024-07-05:
Well, you've shown a lot of determination and perseverance. I'm really happy you made it work, and I'm sure after so much frustration these past few weeks you are now feeling absolutely great. Congratulations!!

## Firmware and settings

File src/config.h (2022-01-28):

#pragma once

//CONSTANTS
#define ADV7280 0
#define ADV7180Q32 1

//CONFIG
#define DECODER ADV7180Q32
#define DEFAULT_SOURCE CVBS
#define DEFAULT_FREERUN false

//BOARD VERSION
#define BOARD_VERSION_MAJOR 3
#define BOARD_VERSION_MINOR 0

//UART
#define SERIAL_PORT_SPEED 38400

//OLED SUPPORT
#define OLED_ENABLED

#if (BOARD_VERSION_MAJOR==2)
//TODO
#elif (BOARD_VERSION_MAJOR==3)
//PINS
#define LED_INPUT PIN_PD5
#define LED_LOCK PIN_PD6
#define LED_SIGNAL PIN_PB1

#define BTN_INPUT PIN_PD3
//#define BTN_MENU PB0
#define BTN_MINUS PIN_PB2 
#define BTN_PLUS PIN_PD7
#define RESET_ADV PIN_PD2
#endif

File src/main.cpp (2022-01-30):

#include <Arduino.h>

#include "config.h"

#include "board.h"
#include "ui.h"
#include "buttons.h"

C2CBoard board = C2CBoard();
UI ui = UI();
static ButtonStateMachine m = ButtonStateMachine();
uint16_t err_init_adv = 0;

void init_pins() {
  pinMode(LED_INPUT , OUTPUT);
  pinMode(LED_LOCK , OUTPUT);
  pinMode(LED_SIGNAL , OUTPUT);
  pinMode(RESET_ADV , OUTPUT);
  pinMode(BTN_INPUT , INPUT);
  pinMode(BTN_MINUS, INPUT);
  pinMode(BTN_PLUS, INPUT);
}

void clear_leds() {
  digitalWrite(LED_INPUT, 0);
  digitalWrite(LED_LOCK, 0);  
  digitalWrite(LED_SIGNAL, 0);
}

void hello_signal() {
  digitalWrite(LED_INPUT, 1);
  digitalWrite(LED_LOCK, 0);  
  digitalWrite(LED_SIGNAL, 1);
  delay(500);
  clear_leds();
}

void init_output() {
  //Init i2c bus
  Wire.begin();
  Wire.setClock(100000L);
  //Init UART
  Serial.begin(SERIAL_PORT_SPEED);
}

void setup() {
  init_pins(); //setup GPIO
  init_output(); //Init UART and I2C
  ui.initUI();
  ui.logo(); //Show splashcreen on available interfaces
  hello_signal(); //blink leds with known pattern
  err_init_adv = board.initVideoPipeline(); //Reset Video decoder and encoder
  digitalWrite(LED_INPUT, 1);
  delay(1000);
  if(err_init_adv==0) {
    digitalWrite(LED_SIGNAL,1); //Signal correct bootup sequence with a short blink
    delay(500);
    clear_leds(); //Initialization ok: clear all leds
    //Set default input configuration (TODO: Read from EEPROM)
    board.setSource(DEFAULT_SOURCE);
    board.setEncoderFreeRun(DEFAULT_FREERUN);
    board.initMenu();
    delay(100);
    initscr();
    ui.clearUI();
  } else {
    ui.info("Error init:", (err_init_adv&0xff00)>>8, err_init_adv&0xff);
  }
}

typedef enum {NORMAL, MENU} mainstatus_t;

void loop() {
  static mainstatus_t userMode = NORMAL; 
  static int healthCounter=0;
  static MenuProvider *menuPointer = 0;
  static bool refreshFlag = true;
  //Step 1: Update UI if needed
  if(err_init_adv!=0){delay(1000);return;}
  bool changed = refreshFlag || board.checkStatusChange();
  if(changed) {
    refreshFlag = false;
    ui.clearUI();
    BoardStatus s = board.getCurrentStatus();
    if(userMode!=MENU) {
      ui.status_mid(s.cvbs, s.locked, s.interlaced, s.ntsc, s.pal, s.secam, s.hz60, 0);
    } else {
      ui.status_top(s.cvbs, s.locked, s.interlaced, s.ntsc, s.pal, s.secam, s.hz60, 0);
      
      //print menu
      MenuItem *item = menuPointer->getVisibleItem();
      if(item->prev()) ui.printMenuItem(-1, item->prev()->getName(), item->prev()->getValue());
      ui.printMenuItem(0, item->getName(), item->getValue());
      if(item->next()) ui.printMenuItem(1, item->next()->getName(), item->next()->getValue());
    }
  }
  if((++healthCounter)%10==0) ui.health();
  delay(50);
  //Step 2: Detect user input
  bool source = digitalRead(BTN_INPUT)==0; //active low
  bool minus = digitalRead(BTN_MINUS)==0;
  bool plus = digitalRead(BTN_PLUS)==0;
  byte buttonStatus = m.step(source, plus, minus);
  if(buttonStatus==0) {
    char userInput = ui.getUserInput();
    buttonStatus = userInput;
  }

  if(userMode==MENU){
    MenuItem *item = menuPointer->getVisibleItem();
    switch(buttonStatus) {
      case 0: break;
      case SOURCE_BUTTON_PRESSED:
        menuPointer = item->action();
        refreshFlag=true;
        if(menuPointer==NULL){userMode=NORMAL;board.browseReset();}
        break;
      case MINUS_BUTTON_PRESSED:
        menuPointer->browseUp();
        refreshFlag=true;
        break;
      case PLUS_BUTTON_PRESSED:
        menuPointer->browseDown();
        refreshFlag=true;
        break;
    }

  } else {
    if(buttonStatus!=0) {
      switch(buttonStatus){
        case SOURCE_BUTTON_PRESSED:
          board.toggleInput();
          refreshFlag=true;
          break;
        case PLUS_BUTTON_PRESSED:
          //board.plus();
          break;
        case MINUS_BUTTON_PRESSED:
          //TODO: Change profile
          //board.minus();
          break;
        case MENU_BUTTON_PRESSED:
          userMode = MENU;
          menuPointer=&board;
          refreshFlag=true;
          break;
      }
    } 
  }
}

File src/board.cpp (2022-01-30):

#include "board.h"

#if (DECODER==ADV7280)
#include "decoder_7280Q32.h"
#define DECODER_CLASS Decoder_7280Q32
#elif (DECODER==ADV7180Q32)
#include "decoder_7180Q32.h"
Decoder_7180Q32 _decoder;
#define DECODER_INSTANCE (&_decoder)
#endif

Encoder _encoder;
#define ENCODER_INSTANCE (&_encoder)

/*******  MENU ITEMS *****/
void encoderFreeRunCallback(MenuProvider *board, byte value) {
  ((C2CBoard*)board)->setEncoderFreeRun(value==0);
}

void C2CBoard::callback() {
  outputComponent = outputColorSpaceItem.getRawValue()==0;
  this->encoder->setOutputColorSpace(outputComponent);
}
/****** C2C Board ******/
C2CBoard::C2CBoard():MenuProvider(F("Menu")), 
  outputColorSpaceItem(this, F("Output"), 0, this)
{
  this->decoder = DECODER_INSTANCE;
  this->encoder = ENCODER_INSTANCE;
}

void C2CBoard::initMenu() {
  outputColorSpaceItem.addValue(F("YPbPr"), F("RGB"));
  this->addItem(&outputColorSpaceItem);

  #ifdef TEST_PATTERN_MENU_ITEM
  encoderFreeRunItem = itemFactory.createDuplet(F("Test Pattern"), F("Off"), F("On"), value, encoderFreeRunCallback);
  value = this->isEncoderFreeRun()?1:0;
  this->addItem(&encoderFreeRunItem);
  #endif
  
  this->getDecoder()->initMenu(this);
  this->addItem(this->getDecoder());  

  this->setRoot(NULL);
}

Decoder *C2CBoard::getDecoder(){
  return decoder;
}

Encoder *C2CBoard::getEncoder(){
  return encoder;
}

uint16_t C2CBoard::initAdv() {
  //Init Decoder
  byte err_dec = this->getDecoder()->reset();
  digitalWrite(LED_INPUT, err_dec==0?1:0);
  //Init Encoder
  byte err_enc = getEncoder()->reset();
  digitalWrite(LED_LOCK, err_enc==0?1:0);
  digitalWrite(LED_SIGNAL, 1);
  getDecoder()->init();
  getEncoder()->init();
  return (((uint16_t)err_dec)<<8) | err_enc;
}

uint16_t C2CBoard::initVideoPipeline() {
  //Reset ADVs
  digitalWrite(RESET_ADV, 1);
  delay(100);
  digitalWrite(RESET_ADV, 0);
  delay(100);
  digitalWrite(RESET_ADV, 1);
  delay(100);
  return this->initAdv();
}

bool C2CBoard::checkStatusChange() {
  bool changesFlag = false;
  DecoderStatus status = getDecoder()->get_status();
  if(status.i2c_error!=0) {
    this->i2c_error_count++;
    if ((i2c_error_count%20)==0) {
      Serial.print("Many i2c err: ");Serial.println(i2c_error_count);
    }
    return false;
  }
  i2c_error_count = 0; //reset after a successfull read of status

  if(!status.equals(this->decoderStatus)){
    decoderStatus = status;
    digitalWrite(LED_LOCK, status.lock?1:0); //Update lock led status
    //init encoder to account for decoder change
    if(decoderStatus.lock) {
      byte ret = getEncoder()->setInterlaced(decoderStatus.interlaced);
      ret += getEncoder()->setPal(decoderStatus.isPAL());
    }
    
    return true;
  } /*else if (userInputFlag) {
    userInputFlag = false;
    print_status();
  }*/
  return false;
}

void C2CBoard::toggleInput() {
  setSource(this->input==CVBS?SVIDEO:CVBS);
}

BoardStatus C2CBoard::getCurrentStatus() {
  DecoderStatus decStatus = this->decoderStatus;
  BoardStatus status;
  status.cvbs = input==CVBS;
  status.hz60 = decStatus.is50hz()==false;
  status.interlaced = decStatus.interlaced;
  status.locked = decStatus.lock;
  status.ntsc = decStatus.isNTSC();
  status.pal = decStatus.isPAL();
  status.secam = decStatus.isSECAM();
  return status;
}

void C2CBoard::setSource(input_t input){
  this->input = input;
  digitalWrite(LED_INPUT, this->input==CVBS?1:0);
  getDecoder()->setSource(this->input==CVBS);
}


//Helper functions

void C2CBoard::disableFreeRun() {
  this->decoderFreeRun=false;
  this->encoderFreeRun=false; 
}

bool C2CBoard::isDecoderFreeRun() {return this->decoderFreeRun;}
void C2CBoard::setDecoderFreeRun(bool active) {
  this->decoderFreeRun = active;
}

bool C2CBoard::isEncoderFreeRun() {return this->encoderFreeRun;}
void C2CBoard::setEncoderFreeRun(bool active) {
  this->encoderFreeRun = active;
  this->getEncoder()->setTestMode(active);
}

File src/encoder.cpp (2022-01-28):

#include "encoder.h"

byte Encoder::setOutputColorSpace(bool component) {
  this->componentOutput=component;
  return send_i2c(ENCODER_ADDR, 0x02, this->componentOutput?0x20:0x10);
}

byte Encoder::setInterlaced(bool interlaced){
  byte ret = 0;
  this->interlaced=interlaced;
  if (this->interlaced) {
    // Disable SD progressive mode
    ret += send_i2c(ENCODER_ADDR, 0x88, 0x00);
  } else {
    // Enable SD progressive mode
    ret += send_i2c(ENCODER_ADDR, 0x88, 0x02);
  }
  return ret;
}

byte Encoder::setTestMode(bool testMode){
  byte ret = 0;
  this->testMode=testMode;
  if(testMode) {
    ret += send_i2c(ENCODER_ADDR, 0x84, 0x40); // Enable color bars
    ret += send_i2c(ENCODER_ADDR, 0x87, 0x00);
    ret += send_i2c(ENCODER_ADDR, 0x88, 0x00);
  } else {
    ret += send_i2c(ENCODER_ADDR, 0x84, 0x06); //Enable SFL 
    ret += send_i2c(ENCODER_ADDR, 0x87, 0x20); //Automatic detection of input format
    ret += this->setInterlaced(this->interlaced);
  }
  if(pal) {
    byte pal_fsc[]={0xCB, 0x8A, 0x09, 0x2A};
    ret += send_i2c_string(ENCODER_ADDR  , 0x8C, pal_fsc, 4);
  } else {
    byte ntsc_fsc[]={0x1F, 0x7C, 0xF0, 0x21};
    ret += send_i2c_string(ENCODER_ADDR  , 0x8C, ntsc_fsc, 4);
  }

  return ret;
}

byte Encoder::setPal(bool pal){
  this->pal = pal;
  return setTestMode(this->testMode);
}


byte Encoder::reset() {
  byte ret = 0;
  ret += send_i2c(ENCODER_ADDR, 0x17, 0x02); // Reset
  delay(10);

  //Common intialization
  ret += send_i2c(ENCODER_ADDR, 0x00, 0x1C); //Dacs ON, PLL ON //0x1E -> PLL OFF
  ret += send_i2c(ENCODER_ADDR, 0x01, 0x00); //SD input mode
  ret += send_i2c(ENCODER_ADDR, 0x80, 0x11);
  // Pixel data valid. YPrPb out. SSAF PrPb filter enabled. Active video edge control enabled.
  ret += send_i2c(ENCODER_ADDR, 0x82, 0xC1);

  return ret;
}

byte Encoder::init() {
  byte ret = 0;
  if(this->testMode==false)
  {
    /*
    56 00 1C ; Power up DACs and PLL
    56 01 00 ; SD only mode
    56 80 10 ; SSAF Luma filter enabled, NTSC mode
    56 82 C9 ; Step control on, pixel data valid, pedestal on, PrPb SSAF on, YPrPb out.
    56 87 20 ; PAL/NTSC autodetect mode enabled
    56 88 00 ; 8 bit input enabled
    */
    ret += setOutputColorSpace(this->componentOutput);
    ret += setTestMode(this->testMode);
    ret += setInterlaced(this->interlaced);
  } else {
    ret += setTestMode(this->testMode);
  }

  return ret;
}

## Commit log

2022-01-28 Board image
2022-01-28 1R3: gerbers and bom Images
    [composite2rgb.bom.csv]
2022-01-28 Better board images
2022-01-28 New menu system and button management code
2022-01-28 Case for 1R3
    [Case_Bottom.stl, Case_Top_Oled.stl, Case_Top_Oled_Logo.stl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]
2024-01-22 Interactive BOM added
2026-07-29 Kicad project
2026-07-30 Step models of the board
